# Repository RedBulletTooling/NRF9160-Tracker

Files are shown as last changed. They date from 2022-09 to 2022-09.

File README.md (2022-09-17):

# NRF9160-Tracker
This is hardware project concept of a CR2032 Operated small size LTE-M/NB-Iot GPS tracker 19x26mm
## Reason
We created these designs and products for our company www.menura.org. If you are in need of custom hardware, software and or solutions that provide digital insights  - please contact us at contact@menura.org 

For us, it's one of those products that would be pretty cool to make but hard to go-to-market with given this only has a very niche legitimate use-case. You will need to provide a back end and front end with adequate independent hosting (could be https://www.traccar.org/). Most tracking providers operate with central servers that they themselves own. They, as sellers, are fully capable of tracking your assets. It doesn't sound all that fun if you realize anyone working at those companies in the right position is fully capable of tracking you and your assets as well if not better than you can. 

Besides that, most trackers are trash or DIY. They use technology from < 2010 and have no single thought for (operational) security or reliability. Using the NRF9160, you now have a small GPS tracker communicating over LTE-M/NB-Iot that uses little energy and can provide the security guarantees you need. Using open-source software (or your in-house C2) you are now also not relient on obscure third party providers.

## Notes
This is a design in concept. This is not yet in production, we are 80% sure this should work as is but still have some things to keep in mind;

1. The antenna design is based on the recommendations of Ignion for EU-based operation. But it is a bit more cramped than they would like. We are unsure of RF performance and this should be tested. We are pretty sure it should work fine we have seen far worse designs in production that work just fine.
2. It's a passive GPS antenna but again design is followed. Unsure of performance.
3. It's a CR2032 battery-based product. Don't expect this to last multiple years. But with proper programming and battery optimization, which the NRF9160 allows for, it should be able to do just fine. We expect 30 days, at the least.
4. Small compromises have been made, and programming is done with a tag connected 6 pin. Debug can be done over those ports either by UART or J-link based debug named RTT. Power is always provided by a battery or external power source threw battery pads.
5. The pads of the battery have shrunken, because of 2 layer design. This shouldn't be a problem, but maybe it could cause some interference on trace running just below it. Those traces aren't that sensitive.
6. Last thing that is pretty major; we are using a 5V LDO that should be able to step up the voltage from the 3V that is received by the battery. Per spec, it should be able to do that just fine but sometimes they don't match the spec.

## Images
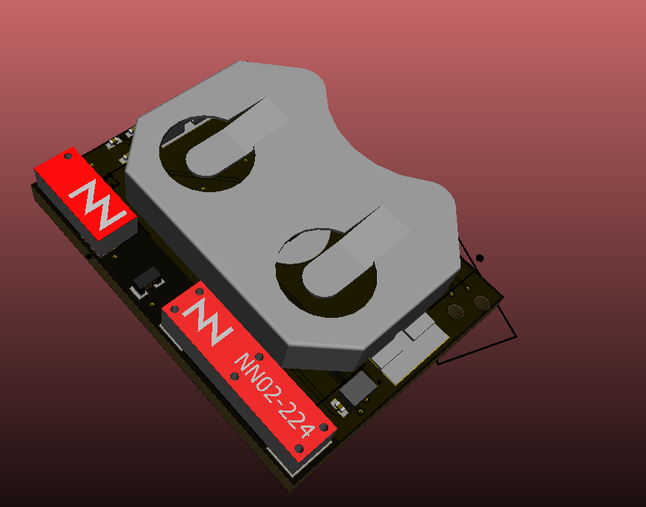
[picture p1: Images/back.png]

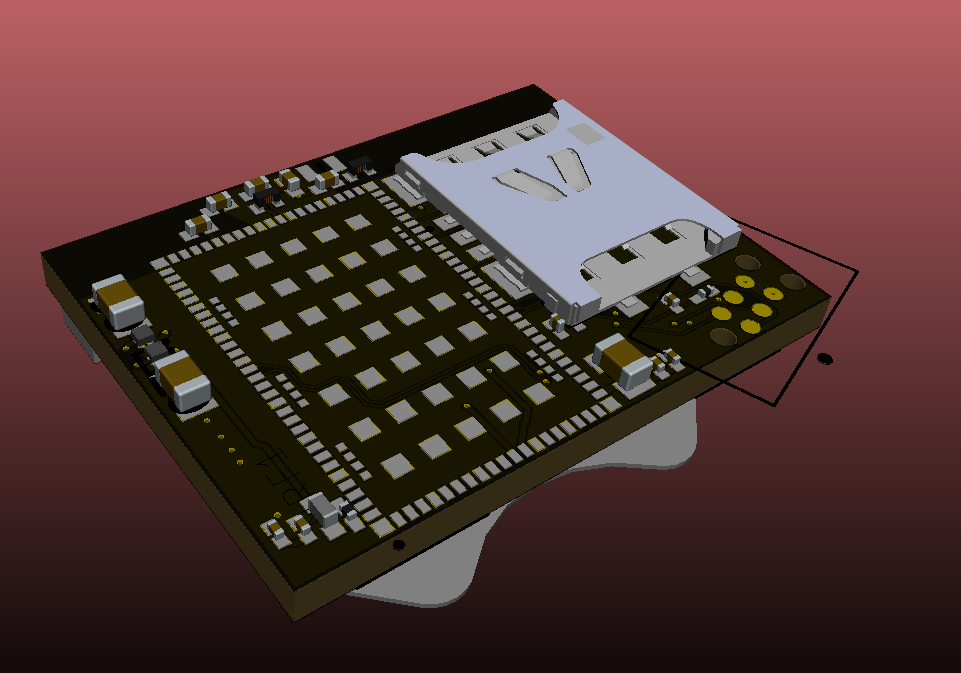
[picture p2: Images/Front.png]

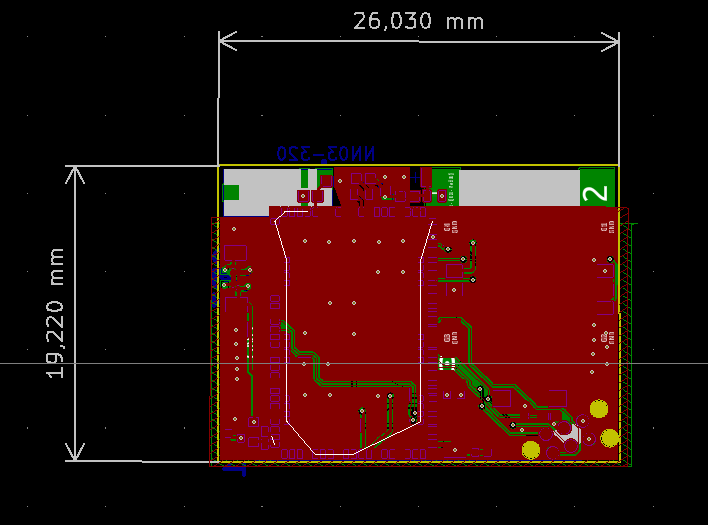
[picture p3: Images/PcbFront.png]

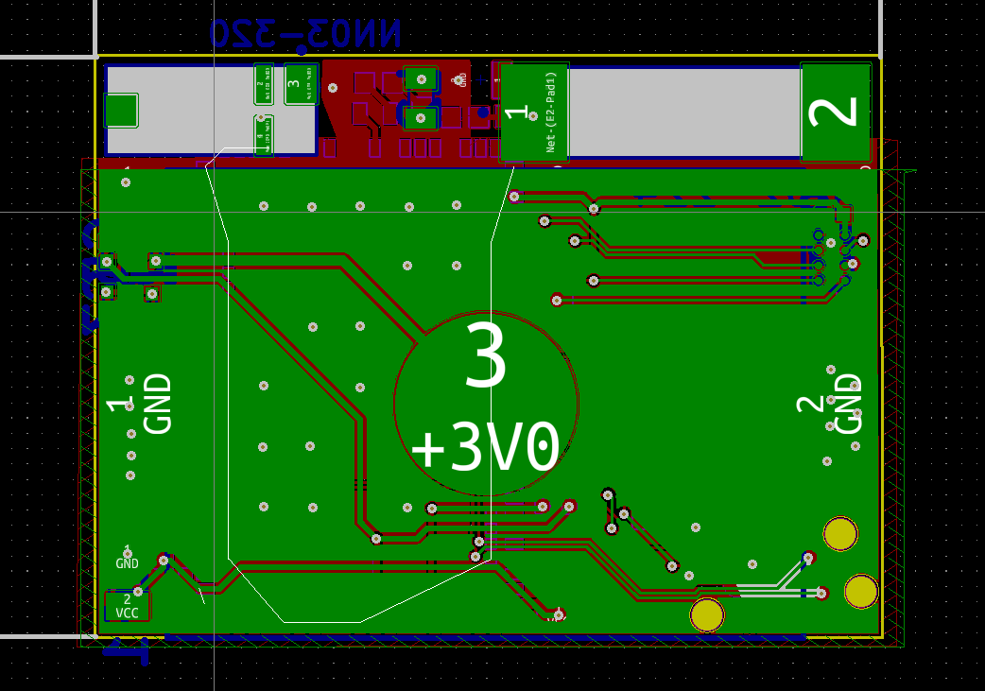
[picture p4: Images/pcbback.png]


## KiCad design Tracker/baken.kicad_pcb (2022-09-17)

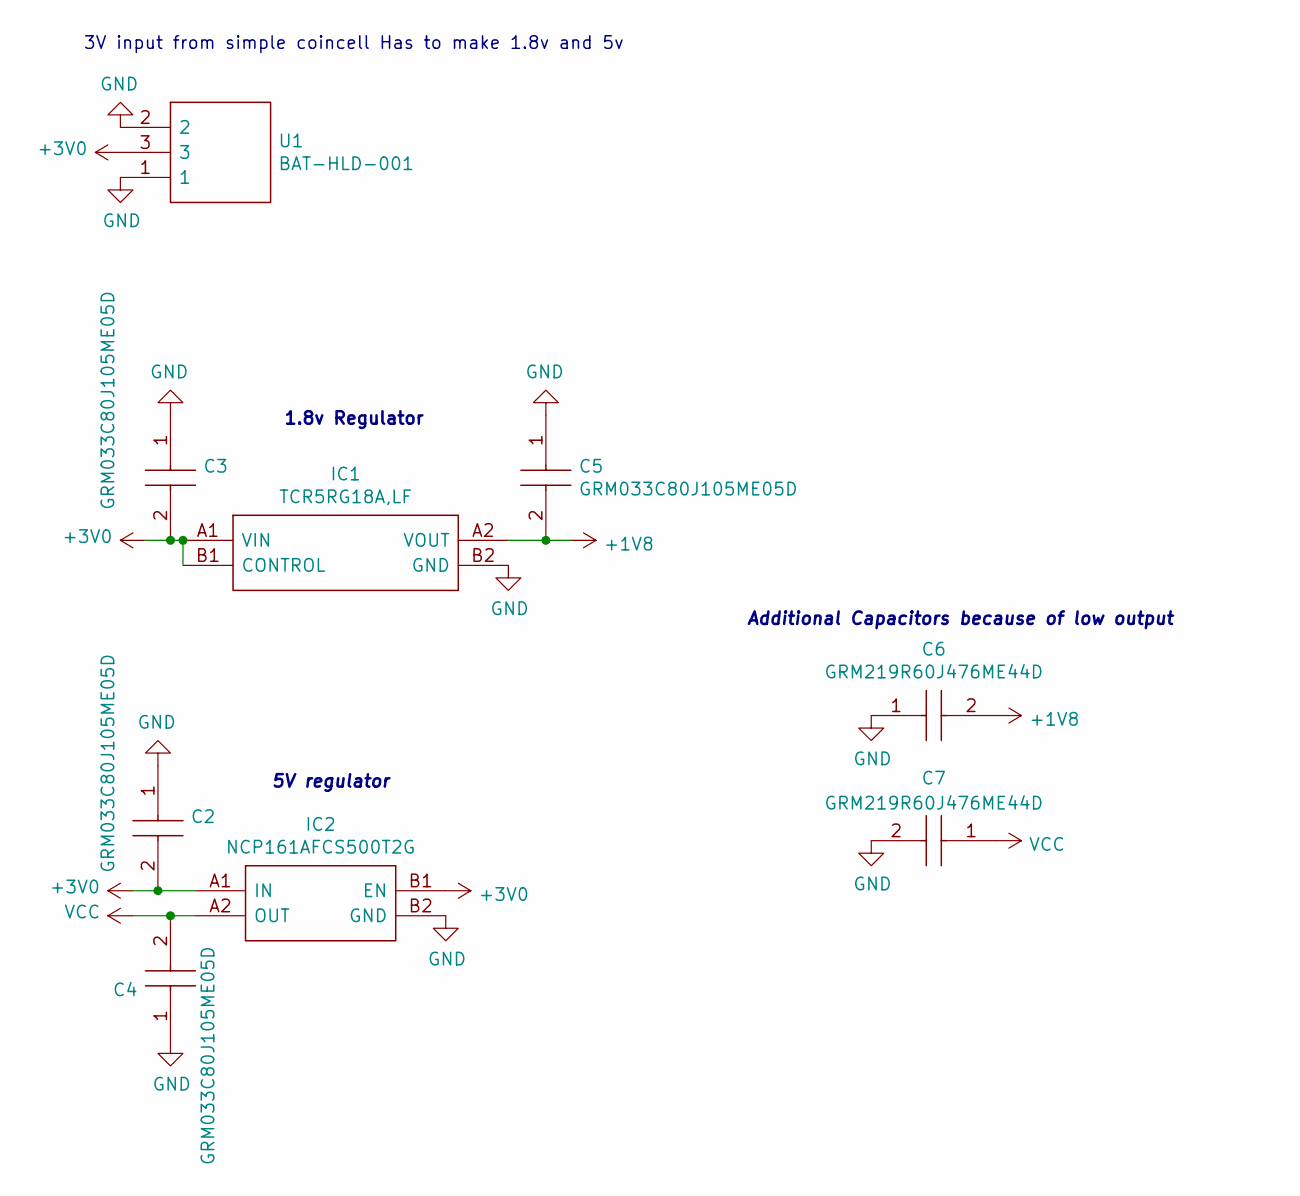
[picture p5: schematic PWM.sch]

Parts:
C2, C3, C4, C5: GRM033C80J105ME05D; CAPC0603X33N; Mouser Part Number 81-GRM033C80J105ME5D
C6, C7: GRM219R60J476ME44D; CAPC2012X95N; Mouser Part Number 81-GRM219R60J476ME4D
IC1: TCR5RG18A,LF; TCR5RG18ALF; Manufacturer_Part_Number TCR5RG18A,LF
IC2: NCP161AFCS500T2G; BGA4C35P2X2_64X64X46; Mouser Part Number 863-NCP161AFCS500T2G
U1: BAT-HLD-001; BATHLD001; Mouser Part Number 712-BAT-HLD-001

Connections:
+1V8: C5.2, C6.2, IC1.A2 (VOUT); also elsewhere on the board
+3V0: C2.2, C3.2, IC1.A1 (VIN), IC1.B1 (CONTROL), IC2.A1 (IN), IC2.B1 (EN), U1.3
GND: C2.1, C3.1, C4.1, C5.1, C6.1, C7.2, IC1.B2 (GND), IC2.B2 (GND), U1.1, U1.2; also elsewhere on the board
VCC: C4.2, C7.1, IC2.A2 (OUT); also elsewhere on the board

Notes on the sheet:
3V input from simple coincell Has to make 1.8v and 5v
1.8v Regulator
5V regulator
Additional Capacitors because of low output

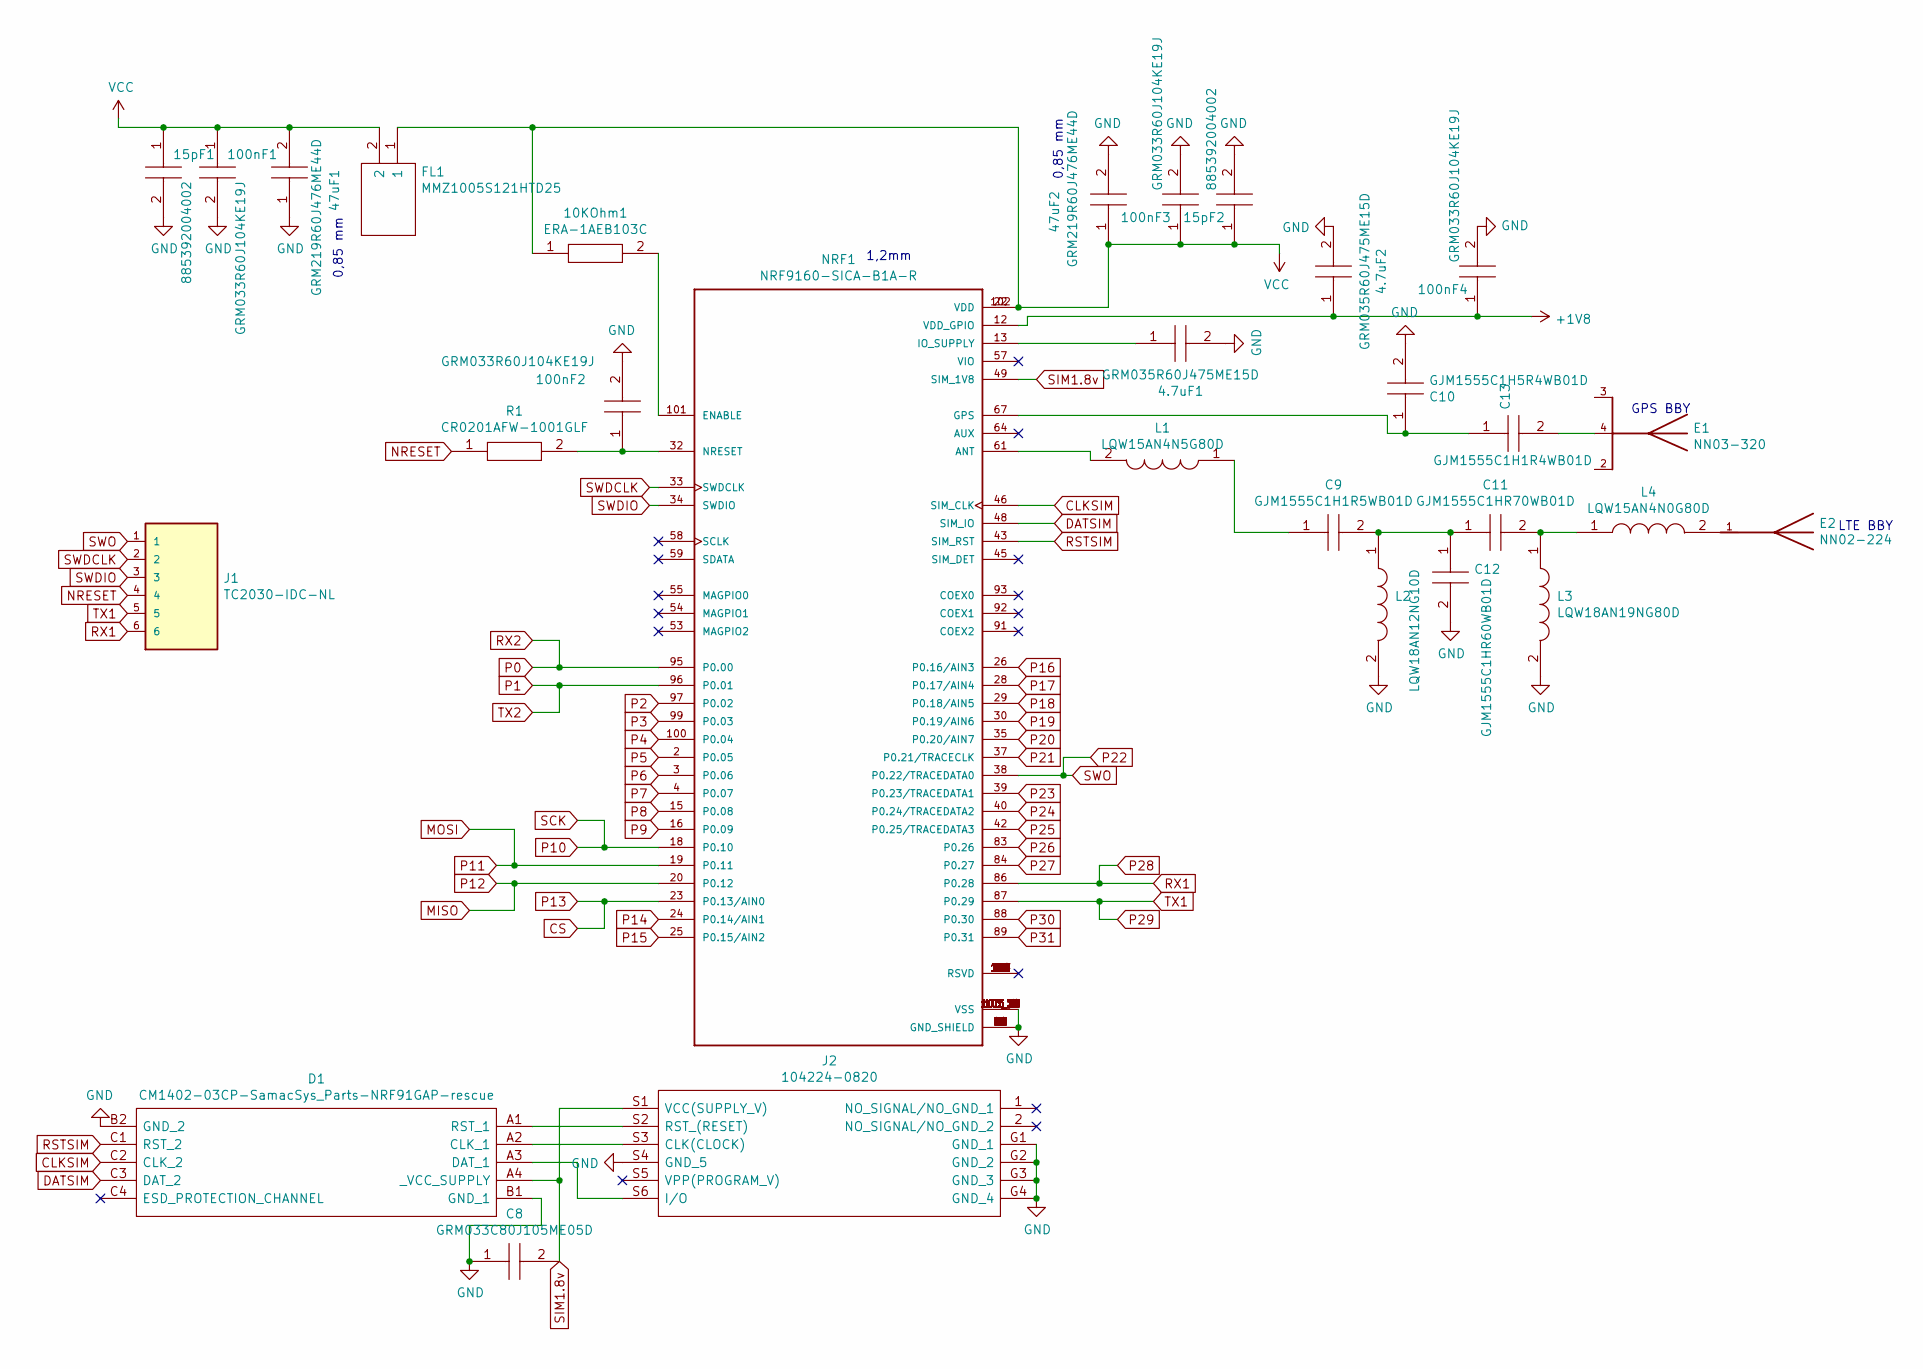
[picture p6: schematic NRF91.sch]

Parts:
4.7uF1, 4.7uF2: GRM035R60J475ME15D; CAPC0603X55N; Mouser Part Number 81-GRM035R60J475ME5D
10KOhm1: ERA-1AEB103C; RESC0603X26N; Mouser Part Number 667-ERA-1AEB103C
15pF1, 15pF2: 885392004002; CAPC0603X33N; Mouser Part Number 710-885392004002
47uF1, 47uF2: GRM219R60J476ME44D; CAPC2012X95N; Mouser Part Number 81-GRM219R60J476ME4D
100nF1, 100nF2, 100nF3, 100nF4: GRM033R60J104KE19J; CAPC0603X33N; Mouser Part Number 81-GRM033R60J104KE9J
C8: GRM033C80J105ME05D; CAPC0603X33N; Mouser Part Number 81-GRM033C80J105ME5D
C9: GJM1555C1H1R5WB01D; CAPC1005X55N; Mouser Part Number 81-GJM1555C1H1R5WB1D
C10: GJM1555C1H5R4WB01D; CAPC1005X55N; Mouser Part Number 81-GJM1555C1H5R4WB1D
C11: GJM1555C1HR70WB01D; CAPC1005X55N; Mouser Part Number 81-GJM1555C1HR70WB1D
C12: GJM1555C1HR60WB01D; CAPC1005X55N; Mouser Part Number 81-GJM1555C1HR60WB1D
C13: GJM1555C1H1R4WB01D; CAPC1005X55N; Manufacturer_Part_Number GJM1555C1H1R4WB01D
D1: CM1402-03CP-SamacSys_Parts-NRF91GAP-rescue; CM140203CP; Mouser Part Number 748-CM1402-03CP
E1: NN03-320; XCVR_NN03-320; PARTREV July 2019
E2: NN02-224; XCVR_NN02-224; PARTREV December 2020
FL1: MMZ1005S121HTD25; BEADC1005X55N; Mouser Part Number 810-MMZ1005S121HTD25
J1: TC2030-IDC-NL; TAG_TC2030-IDC-NL; PARTREV MS
J2: 104224-0820; 1042240820; Mouser Part Number 538-104224-0820
L1: LQW15AN4N5G80D; LQW15AN10NG80D; Manufacturer_Part_Number LQW15AN4N5G80D
L2: LQW18AN12NG10D; LQW18AS10NG0CD; Mouser Part Number 81-LQW18AN12NG10D
L3: LQW18AN19NG80D; LQW18AN10NG80D; Mouser Part Number 81-LQW18AN19NG80D
L4: LQW15AN4N0G80D; LQW15AN10NG80D; Manufacturer_Part_Number LQW15AN4N0G80D
NRF1: NRF9160-SICA-B1A-R; XCVR_NRF9160-SICA-R
R1: CR0201AFW-1001GLF; RESC0603X26N; Mouser Part Number 652-CR0201AFW1001GLF

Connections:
+1V8: 4.7uF2.1, 100nF4.1, NRF1.12 (VDD_GPIO); also elsewhere on the board
CLKSIM: D1.C2 (CLK_2), NRF1.46 (SIM_CLK)
CS: NRF1.23 (P0.13/AIN0)
DATSIM: D1.C3 (DAT_2), NRF1.48 (SIM_IO)
GND: 4.7uF1.2, 4.7uF2.2, 15pF1.2, 15pF2.2, 47uF1.1, 47uF2.2, 100nF1.2, 100nF2.2, 100nF3.2, 100nF4.2, C8.1, C10.2, C12.2, D1.B1 (GND_1), D1.B2 (GND_2), J2.G1 (GND_1), J2.G2 (GND_2), J2.G3 (GND_3), J2.G4 (GND_4), J2.S4 (GND_5), L2.2, L3.2, NRF1.1 (GND_SHIELD), NRF1.5 (GND_SHIELD), NRF1.9 (GND_SHIELD), NRF1.14 (GND_SHIELD), NRF1.17 (GND_SHIELD), NRF1.21 (GND_SHIELD), NRF1.27 (GND_SHIELD), NRF1.31 (GND_SHIELD), NRF1.36 (GND_SHIELD), NRF1.41 (GND_SHIELD), NRF1.44 (GND_SHIELD), NRF1.47 (GND_SHIELD), NRF1.50 (GND_SHIELD), NRF1.52 (GND_SHIELD), NRF1.56 (GND_SHIELD), NRF1.60 (GND_SHIELD), NRF1.62 (GND_SHIELD), NRF1.63 (GND_SHIELD), NRF1.65 (GND_SHIELD), NRF1.66 (GND_SHIELD), NRF1.72 (GND_SHIELD), NRF1.74 (GND_SHIELD), NRF1.75 (GND_SHIELD), NRF1.76 (GND_SHIELD), NRF1.77 (GND_SHIELD), NRF1.78 (GND_SHIELD), NRF1.79 (GND_SHIELD), NRF1.80 (GND_SHIELD), NRF1.81 (GND_SHIELD), NRF1.82 (GND_SHIELD), NRF1.85 (GND_SHIELD), NRF1.90 (GND_SHIELD), NRF1.94 (GND_SHIELD), NRF1.98 (GND_SHIELD), NRF1.103_1 (VSS), NRF1.103_2 (VSS), NRF1.103_3 (VSS), NRF1.103_4 (VSS), NRF1.103_5 (VSS), NRF1.103_6 (VSS), NRF1.103_7 (VSS), NRF1.103_8 (VSS), NRF1.103_9 (VSS), NRF1.103_10 (VSS), NRF1.103_11 (VSS), NRF1.103_12 (VSS), NRF1.103_13 (VSS), NRF1.103_14 (VSS), NRF1.103_15 (VSS), NRF1.103_16 (VSS), NRF1.103_17 (VSS), NRF1.103_18 (VSS), NRF1.103_19 (VSS), NRF1.103_20 (VSS), NRF1.103_21 (VSS), NRF1.103_22 (VSS), NRF1.103_23 (VSS), NRF1.103_24 (VSS), NRF1.103_25 (VSS), NRF1.103_26 (VSS), NRF1.103_27 (VSS), NRF1.103_28 (VSS), NRF1.103_29 (VSS), NRF1.103_30 (VSS), NRF1.103_31 (VSS), NRF1.103_32 (VSS), NRF1.103_33 (VSS), NRF1.103_34 (VSS), NRF1.103_35 (VSS); also elsewhere on the board
MISO: NRF1.20 (P0.12)
MOSI: NRF1.19 (P0.11)
NRESET: J1.4, R1.1
unnamed: 4.7uF1.1, NRF1.13 (IO_SUPPLY)
unnamed: 10KOhm1.2, NRF1.101 (ENABLE)
unnamed: 100nF2.1, NRF1.32 (NRESET), R1.2
unnamed: C9.1, L1.1
unnamed: C10.1, C13.1, NRF1.67 (GPS)
unnamed: C9.2, C11.1, C12.1, L2.1
unnamed: C11.2, L3.1, L4.1
unnamed: C13.2, E1.4
unnamed: D1.A1 (RST_1), J2.S2 (RST_(RESET))
unnamed: D1.A2 (CLK_1), J2.S3 (CLK(CLOCK))
unnamed: D1.A3 (DAT_1), J2.S6 (I/O)
unnamed: E2.1, L4.2
unnamed: L1.2, NRF1.61 (ANT)
unnamed: NRF1.6 (RSVD), NRF1.7 (RSVD), NRF1.8 (RSVD), NRF1.10 (RSVD), NRF1.11 (RSVD), NRF1.51 (RSVD), NRF1.68 (RSVD), NRF1.69 (RSVD), NRF1.70 (RSVD), NRF1.71 (RSVD), NRF1.73 (RSVD), NRF1.104 (RSVD), NRF1.105 (RSVD), NRF1.106 (RSVD), NRF1.107 (RSVD), NRF1.108 (RSVD), NRF1.109 (RSVD), NRF1.110 (RSVD), NRF1.111 (RSVD), NRF1.112 (RSVD), NRF1.113 (RSVD), NRF1.114 (RSVD), NRF1.115 (RSVD), NRF1.116 (RSVD), NRF1.117 (RSVD), NRF1.118 (RSVD), NRF1.119 (RSVD), NRF1.120 (RSVD), NRF1.121 (RSVD), NRF1.122 (RSVD), NRF1.123 (RSVD), NRF1.124 (RSVD), NRF1.125 (RSVD), NRF1.126 (RSVD), NRF1.127 (RSVD)
P0: NRF1.95 (P0.00)
P1: NRF1.96 (P0.01)
P2: NRF1.97 (P0.02)
P3: NRF1.99 (P0.03)
P4: NRF1.100 (P0.04)
P5: NRF1.2 (P0.05)
P6: NRF1.3 (P0.06)
P7: NRF1.4 (P0.07)
P8: NRF1.15 (P0.08)
P9: NRF1.16 (P0.09)
P10: NRF1.18 (P0.10)
P14: NRF1.24 (P0.14/AIN1)
P15: NRF1.25 (P0.15/AIN2)
P16: NRF1.26 (P0.16/AIN3)
P17: NRF1.28 (P0.17/AIN4)
P18: NRF1.29 (P0.18/AIN5)
P19: NRF1.30 (P0.19/AIN6)
P20: NRF1.35 (P0.20/AIN7)
P21: NRF1.37 (P0.21/TRACECLK)
P22: J1.1, NRF1.38 (P0.22/TRACEDATA0)
P23: NRF1.39 (P0.23/TRACEDATA1)
P24: NRF1.40 (P0.24/TRACEDATA2)
P25: NRF1.42 (P0.25/TRACEDATA3)
P26: NRF1.83 (P0.26)
P27: NRF1.84 (P0.27)
P28: J1.6, NRF1.86 (P0.28)
P29: J1.5, NRF1.87 (P0.29)
P30: NRF1.88 (P0.30)
P31: NRF1.89 (P0.31)
RSTSIM: D1.C1 (RST_2), NRF1.43 (SIM_RST)
SIM1.8v: C8.2, D1.A4 (_VCC_SUPPLY), J2.S1 (VCC(SUPPLY_V)), NRF1.49 (SIM_1V8)
SWDCLK: J1.2, NRF1.33 (SWDCLK)
SWDIO: J1.3, NRF1.34 (SWDIO)
VCC: 10KOhm1.1, 15pF1.1, 15pF2.1, 47uF1.2, 47uF2.1, 100nF1.1, 100nF3.1, FL1.1, FL1.2, NRF1.22 (VDD), NRF1.102 (VDD); also elsewhere on the board

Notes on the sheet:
0,85 mm
1,2mm
GPS BBY
LTE BBY

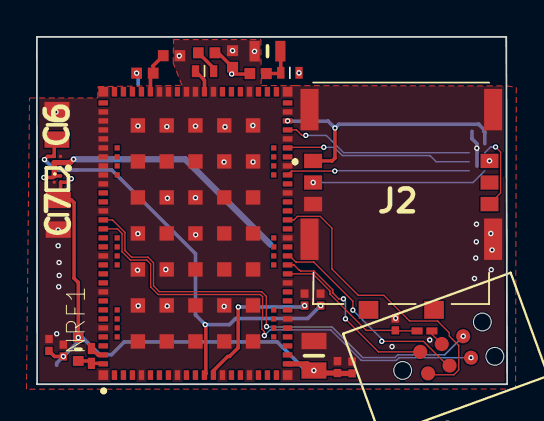
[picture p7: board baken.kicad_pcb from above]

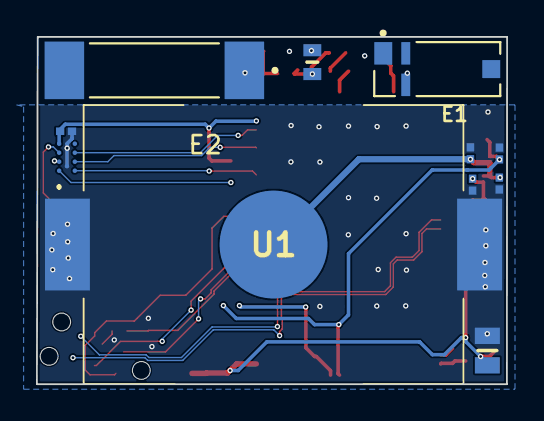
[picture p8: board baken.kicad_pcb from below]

Board: 2 copper layers, 26.1 x 19.3 mm, 37 parts (11 on the bottom side), 28 nets.

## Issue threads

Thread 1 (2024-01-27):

Does it work?

sascha-hemi, 2024-01-27:
Hi,

we have a so-called "RX Chip" that got submerged in water. It´s a little GPS-Tracker for an E-Bike.
Now we want to make our own solution for it.
The existing chip receives a 12V power supply as soon as the E-Bike is turned on to charge the internal battery.
So, we don't need the CR2032, but instead, we require a Battery Gauge and Charging IC to charge a Li-Po cell and also detect the battery level.
Did you test the PCB? I know nothing about the NRF9160 😄
But i can use KiCad 😄

The "RX Chip" is the small white component. Normally, it sits behind a plastic casing near the bike motor.
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

RedBulletTooling, 2024-01-27:
Heya,

I am not sure it will work. I basic jou will need to do some testing. Furthermore the LDO is not 12v capabel I think you will need too redesign. Also the nrf9160 is not very user friendly nor a package you can hand solder so cost will always be high. Low order of 5-10 will always be 500+ euro’s in china. I dont recommend you using this project unless you’re more comfortable. You could buy a nrf91 devkit and test or a feather nrf91.

RedBulletTooling, 2024-01-27:
Heya,

I am not sure it will work. I basic jou will need to do some testing. Furthermore the LDO is not 12v capabel I think you will need too redesign. Also the nrf9160 is not very user friendly nor a package you can hand solder so cost will always be high. Low order of 5-10 will always be 500+ euro’s in china. I dont recommend you using this project unless you’re more comfortable. You could buy a nrf91 devkit and test or a feather nrf91.
